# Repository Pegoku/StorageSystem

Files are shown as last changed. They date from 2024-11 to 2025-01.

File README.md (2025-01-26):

# Smart Storage System

## Overview
This is a versatile and customizable Storage System. It has the ability to combine multiple Storage Systems via the use of ESP32 (a cheap microcontroller) as controllers for the neopixels (indicators). It has a simple but useful WebUI and an API. The storage bins are compatible with Gridfinity 1x4 bins.

## Features
- [x] **Gridfinity Compatible**: Easily integrates with the Gridfinity storage system for modular storage.
- [x] **Parametric Design**: Easily customizable bins.
- [x] **ESP32 Controlled**: Scalable system using ESP32 as wireless controllers.
- [x] **Neopixels**: Dynamic lighting indicators.
- [x] **Web UI to Manage Storage**: User-friendly web interface for managing the items.
- [x] **API**: Simple to use API.
- [x] **Node PCB**: Simple ESP32-Wroom based PCB with the necessary connectors.

## Media
<details>
    <summary>Main Website</summary>

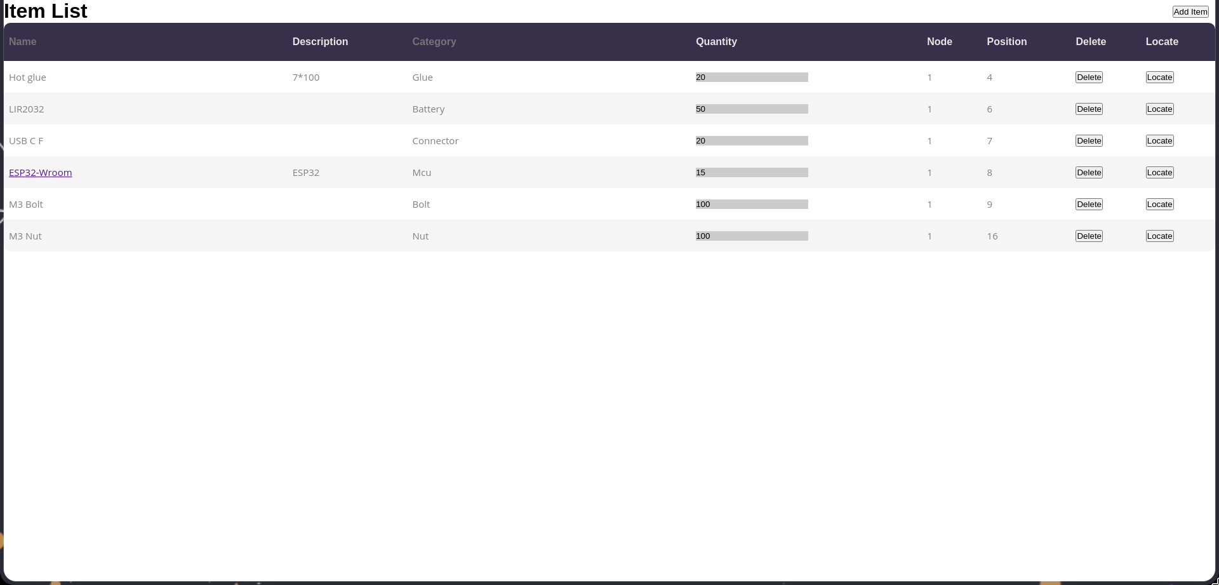
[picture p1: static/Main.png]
Main Website

</details>

<details>
    <summary>Add Item Menu</summary>

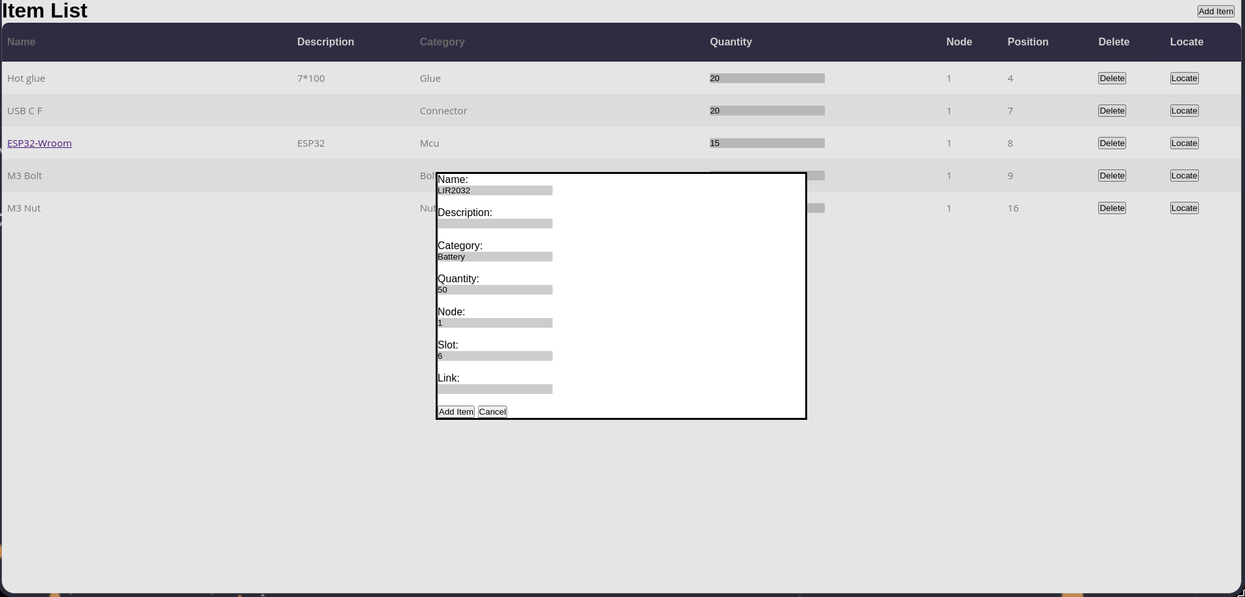
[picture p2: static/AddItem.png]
Add Item Menu

</details>

<details>
    <summary>Video</summary>

Video (https://cloud-f5ibtbvt0-hack-club-bot.vercel.app/0video.mp4)

</details>

## API Endpoints

### List Storage Items
- **Endpoint**: `/api/list`
- **Method**: `GET`
- **Description**: Retrieves a list of all storage items. Supports optional query parameters for filtering by category, node, and position.
- **Query Parameters**:
  - `category` (optional): Filter items by category.
  - `node` (optional): Filter items by node.
  - `position` (optional): Filter items by position.
  - `id` (optional): Filter items by ID:
### Locate Item by ID (GET)
- **Endpoint**: `/api/locateget`
- **Method**: `GET`
- **Description**: Locates an item by its ID and sends a request to the corresponding node to locate the item.
- **Query Parameters**:
  - `id` (required): The ID of the item to locate.

### List Nodes
- **Endpoint**: `/api/nodes`
- **Method**: `GET`
- **Description**:  Retrieves a list of all nodes. Supports optional query parameter for filtering by ID.
- **Query Parameters**:
    - `id` (optional): Filter nodes by ID.

### Add Storage Item
- **Endpoint**: `/api/additem`
- **Method**: `POST`
- **Description**: Adds a new storage item to the database.
- **Request Body** (JSON):
  ```json
  {
    "name": "string",
    "description": "string",
    "category": "string",
    "quantity": "integer",
    "node": "integer",
    "position": "integer",
    "url": "string",
    "slots": "array"

  }
  ```

### Add Node
- **Endpoint**: `/api/addnode`
- **Method**: `POST`
- **Description**:  Adds a new node to the database or updates an existing node if the ID already exists.
- **Request Body** (JSON):
  ```json
    {
      "id": "integer",
      "ip": "string",
      "positions": "integer"
    }
  ```

### Delete Storage Item
- **Endpoint**: `/api/delete`
- **Method**: `POST`
- **Description**:   Deletes a storage item by its ID.
- **Request Body** (JSON):
  ```json
    {
      "id": "integer"
    }
  ```

### Edit Storage Item
- **Endpoint**: `/api/edit`
- **Method**: `POST`
- **Description**:  Edits an existing storage item by its ID.
- **Request Body** (JSON):
  ```json
    {
    "id": "integer",
    "name": "string",
    "description": "string",
    "category": "string",
    "quantity": "integer",
    "node": "integer",
    "position": "integer",
    "url": "string",
    "slots": "array"
    }   
  ```

### Move Storage Item
- **Endpoint**: `/api/move`
- **Method**: `POST`
- **Description**:  Moves a storage item to a different node and position.
- **Request Body** (JSON):
  ```json
    {
    "id": "integer",
    "node": "integer",
    "position": "integer"
    }
  ```

### Locate Item by ID (POST)
- **Endpoint**: `/api/locate`
- **Method**: `POST`
- **Description**:  Locates an item by its ID and sends a request to the corresponding node to locate the item.
- **Request Body** (JSON):
  ```json
    {
    "id": "integer"
    }
  ```

## Getting Started

### Prerequisites
- [PlatformIO](https://platformio.org) installed on your development environment.
- ESP32 DevBoard or [Node PCB](https://github.com/Pegoku/StorageSystem/tree/master/PCB/NodePCB) .
- Neopixels (WS2812B) or [Indicator PCB](https://github.com/Pegoku/StorageSystem/tree/master/PCB/Indicators).
- Some wire.
- Edit Code/App/static/script.js `server` variable
- Edit Code/Node/include/.env with the correct settings

### Docker (API + Website)
1. Clone the repository:
    ```sh
    git clone https://github.com/Pegoku/StorageSystem.git
    cd StorageSystem
    ```
2. Build and run the Docker containers:
  ```sh
  docker compose up -d --build
  ```

### API 
1. Clone the repository:
    ```sh
    git clone https://github.com/Pegoku/StorageSystem.git
    cd StorageSystem/Code/Server
    ```
2. Create a Python virtual environment and install the requirements:
    ```sh
    python3 -m venv .venv
    source .venv/bin/activate
    pip install -r requirements.txt
    ```
3. Run the main Python file:
    ```sh
    python3 main.py
    ```

### API (Docker)
1. Clone the repository:
  ```sh
  git clone https://github.com/Pegoku/StorageSystem.git
  cd StorageSystem
  ```
2. Build and run the Docker container:
  ```sh
  docker buildx build -t storagesystem:server -f server.Dockerfile .
  docker run -p 5505:5505 -v ./database.db:/app/database.db storagesystem:server
  ```
3. The API should now be running and accessible at `http://localhost:5505`.

### ESP32
1. Clone the repository:
    ```sh
    git clone https://github.com/Pegoku/StorageSystem.git
    cd StorageSystem
    ```
2. Install the required libraries and dependencies:
    ```sh
    platformio run
    ```
3. Connect your ESP32 to your computer.
4. Edit the `include/.env.template` file and rename it to `include/.env`.
5. Upload the firmware to the ESP32:
    ```sh
    platformio run --target upload
    ```
6. Open the serial monitor to check if the installation was successful:
    ```sh
    platformio device monitor
    ```

### Website
1. Clone the repository:
    ```sh
    git clone https://github.com/Pegoku/StorageSystem.git
    cd StorageSystem/Code/App
    ```
2. Create a Python virtual environment and install the requirements:
    ```sh
    python3 -m venv .venv
    source .venv/bin/activate
    pip install -r requirements.txt
    ```
3. Run the main Python file:
    ```sh
    python3 main.py
    ```

### Website (Docker)
1. Clone the repository:
  ```sh
  git clone https://github.com/Pegoku/StorageSystem.git
  cd StorageSystem
  ```
2. Build and run the Docker container:
  ```sh
  docker buildx build -t storagesystem:app -f app.Dockerfile .
  docker run -p 5506:5506 storagesystem:app
  ```
3. The website should now be running and accessible at `http://localhost:5506`.

## Contributing
Contributions are welcome! Please fork the repository and submit a pull request with your changes.

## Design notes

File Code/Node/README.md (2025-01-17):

Code for the ESP32
## Important

Make sure to configure the include/.env file correctly

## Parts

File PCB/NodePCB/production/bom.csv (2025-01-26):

Designator | Footprint | Quantity | Value | LCSC Part #
D1 | SOD-323_L1.8-W1.3-LS2.5-RD | 1 | NSR0320MW2T1G | C48192
J1 | PinHeader_1x04_P2.54mm_Horizontal | 1 | Conn_01x04
J2, J3 | PinHeader_1x03_P2.54mm_Horizontal | 2 | Conn_01x03_Pin
J4, J5 | PinHeader_1x10_P2.54mm_Vertical | 2 | Conn_01x10
LED1 | LED0805-R-RD | 1 | FC-2012HRK-620D | C84256
R1 | 0603 | 1 | 1k
R2, R3 | 0603 | 2 | 5.1k
R4 | 0603 | 1 | 68
SW1, SW2 | SW-SMD_L3.9-W3.0-P4.45 | 2 | TS-1088-AR02016 | C720477
U1 | COMM-SMD_ESP-WROOM-32D | 1 | ESP-WROOM-32E | C19949066
U2 | SOT-223-3_L6.5-W3.4-P2.30-LS7.0-BR | 1 | LM2940S-3.3 | C596335
USB1 | TYPE-C-SMD_TYPE-C-6P_5 | 1 | TYPE-C 6P(073) | C668623

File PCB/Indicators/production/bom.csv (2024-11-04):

Designator | Footprint | Quantity | Value | LCSC Part #
C1 | 0603 | 1 | C | C2844328
J1, J2 | PinHeader_1x03_P2.54mm_Horizontal | 2 | Conn_01x03
J3, J4 | PinSocket_1x03_P2.54mm_Horizontal | 2 | Conn_01x03
LED1 | LED-SMD_4P-L5.0-W5.0-BL_TC5050RGB | 1 | WS2812B-B | C114586
TP1, TP2, TP3, TP4, TP5, TP6 | TestPoint_Pad_D1.5mm | 6 | TestPoint

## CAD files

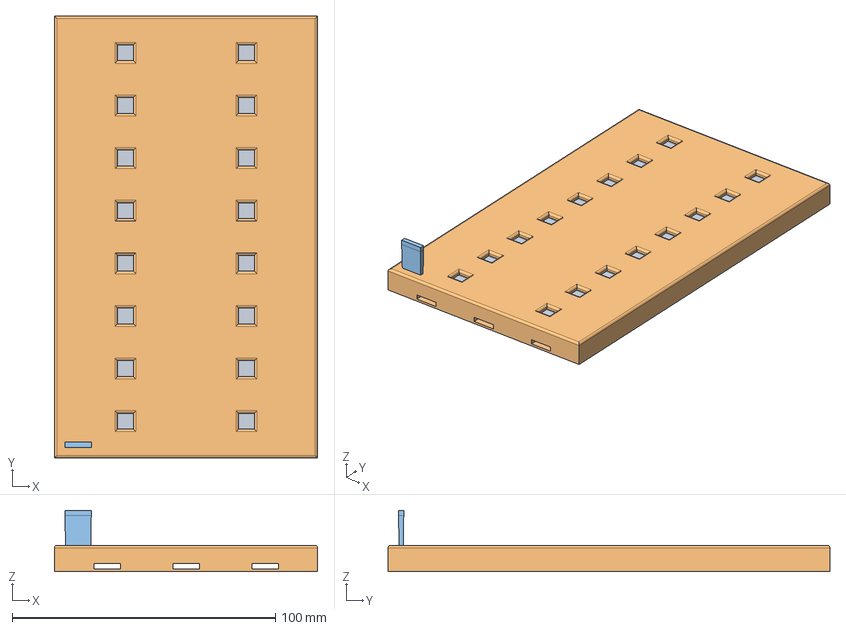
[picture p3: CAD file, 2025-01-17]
3D/Main.FCStd
100.0 x 168.0 x 23.3 mm
SlotIndicatorBack
SlotIndicatorCover
SlotIndicatorPin

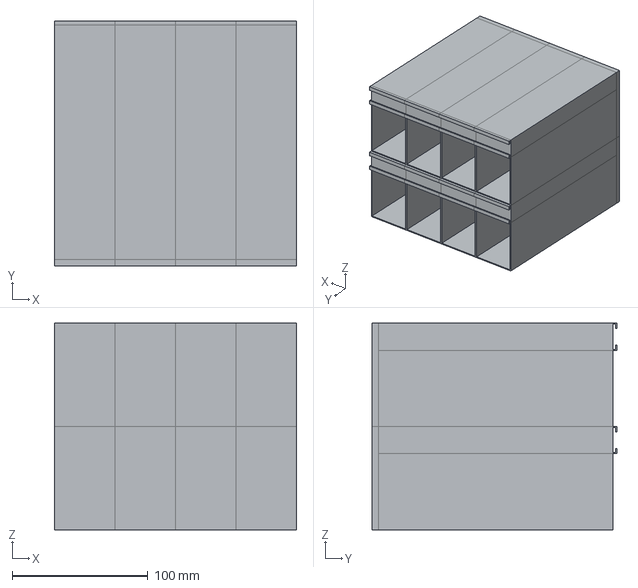
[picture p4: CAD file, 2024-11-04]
3D/Main-Body004.step
178.0 x 180.5 x 152.0 mm

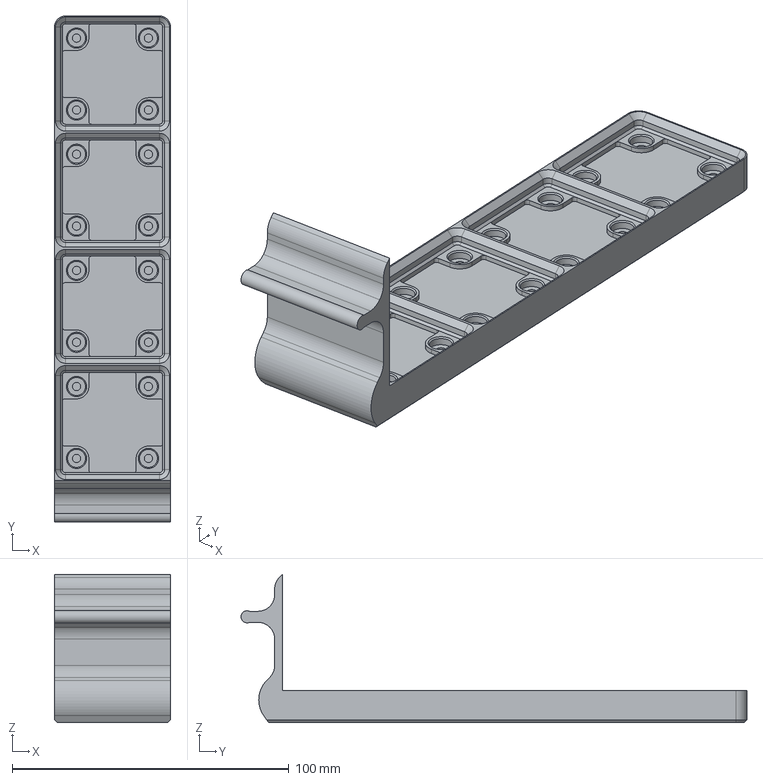
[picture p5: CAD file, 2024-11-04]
3D/Main-PartBody001.step
42.0 x 183.0 x 53.6 mm

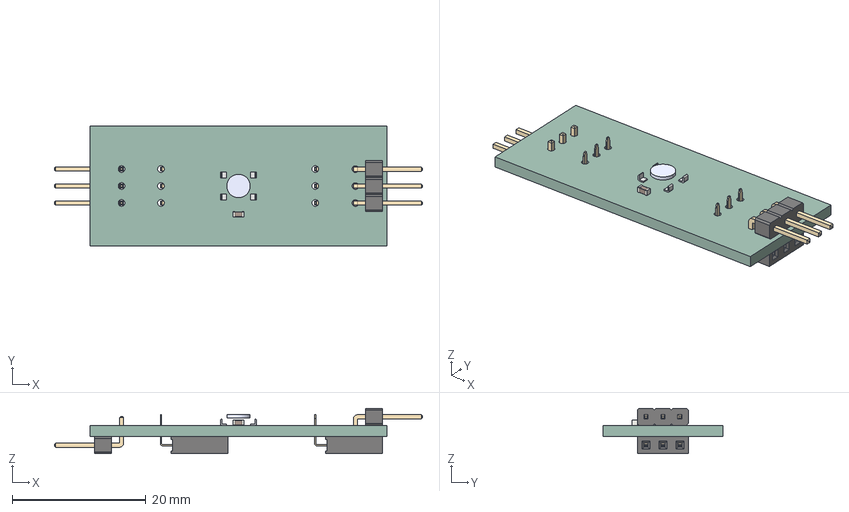
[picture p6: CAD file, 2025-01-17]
PCB/Indicators/Indicators.step
55.1 x 18.0 x 6.78 mm
C_0603_1608Metric
PinHeader_1x03_P254mm_Horizontal x 2
LED-SMD_4P-L5.0-W5.0-BL_TC5050RGB
PinSocket_1x03_P254mm_Horizontal x 2
Indicators_PCB

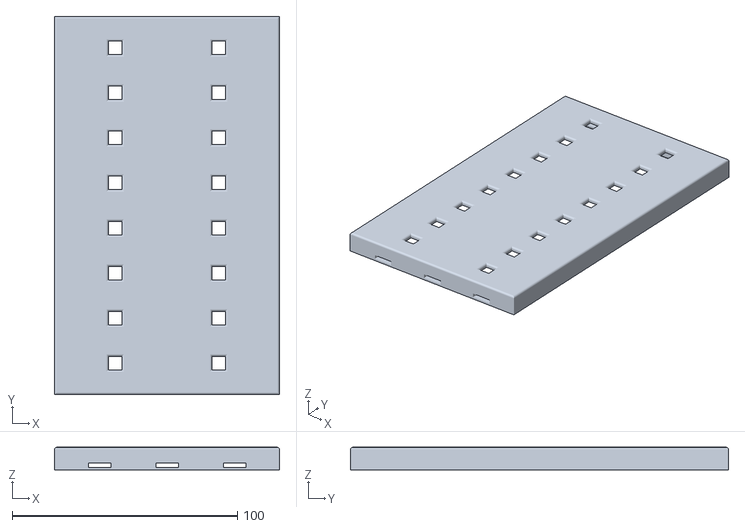
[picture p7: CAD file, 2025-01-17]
3D/SlotIndicatorCover.stl
100.0 x 168.0 x 10.0

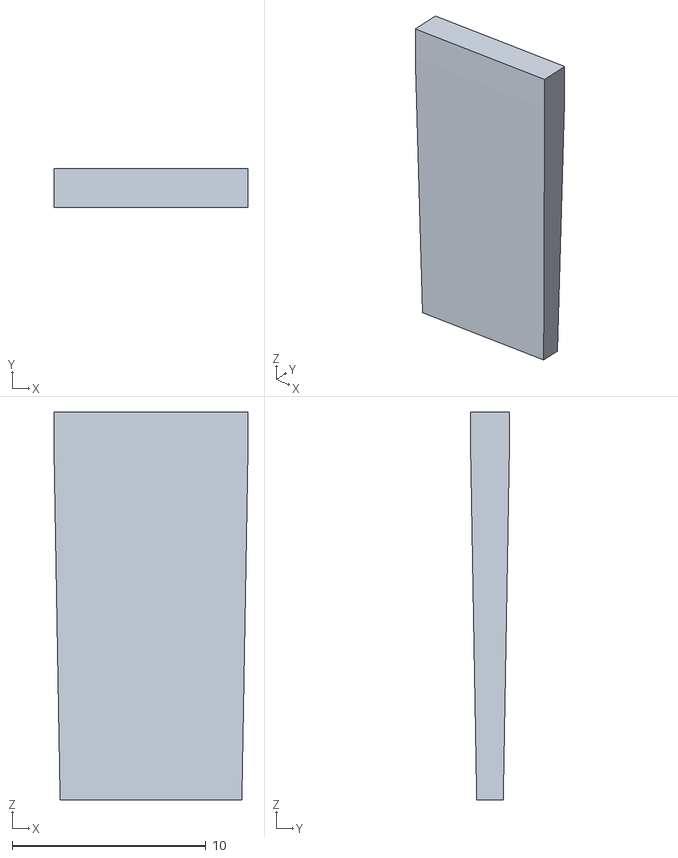
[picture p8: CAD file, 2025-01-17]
3D/SlotIndicatorPin.stl
10.0 x 2.00 x 20.0

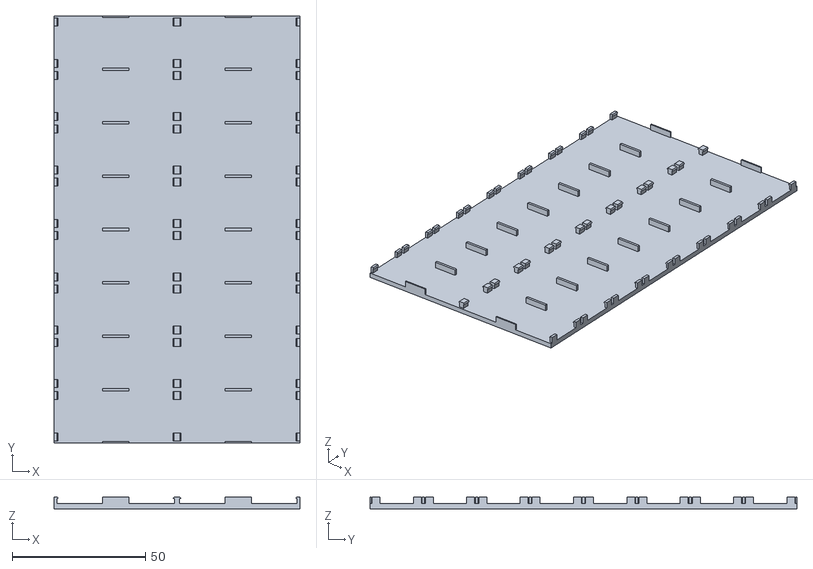
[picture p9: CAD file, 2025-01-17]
3D/SlotIndicatorBack.stl
92.0 x 160.0 x 4.50

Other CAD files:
3D/Tray.step
3D/Box.step
3D/Box.stl
3D/Tray.stl

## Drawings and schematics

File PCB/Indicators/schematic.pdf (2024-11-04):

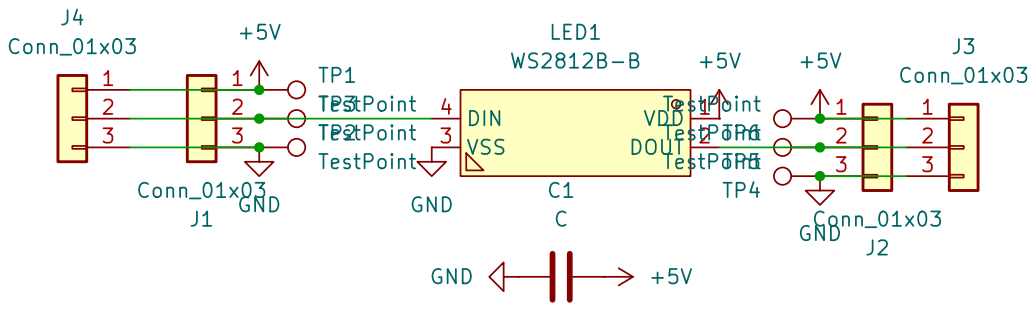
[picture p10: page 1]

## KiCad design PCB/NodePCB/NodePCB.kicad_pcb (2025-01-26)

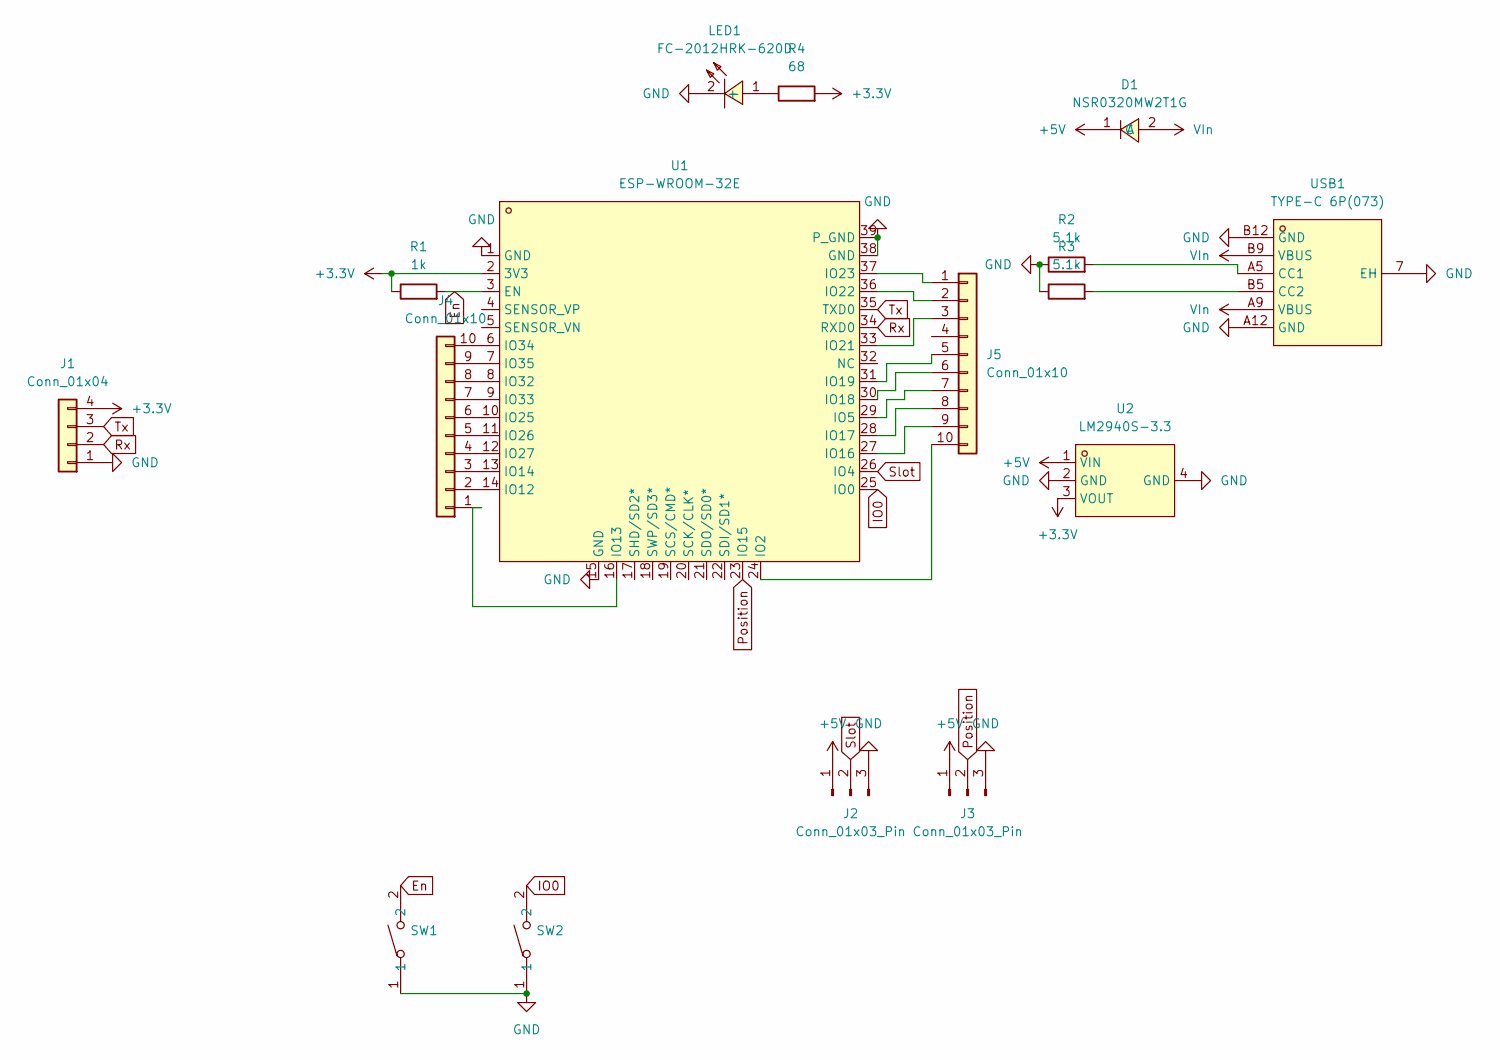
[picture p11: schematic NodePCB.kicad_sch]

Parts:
D1: NSR0320MW2T1G; SOD-323_L1.8-W1.3-LS2.5-RD; LCSC Part C48192
J1: Conn_01x04; PinHeader_1x04_P2.54mm_Horizontal
J2, J3: Conn_01x03_Pin; PinHeader_1x03_P2.54mm_Horizontal
J4, J5: Conn_01x10; PinHeader_1x10_P2.54mm_Vertical
LED1: FC-2012HRK-620D; LED0805-R-RD; LCSC Part C84256
R1: 1k; R_0603_1608Metric
R2, R3: 5.1k; R_0603_1608Metric
R4: 68; R_0603_1608Metric
SW1, SW2: TS-1088-AR02016; SW-SMD_L3.9-W3.0-P4.45; LCSC Part C720477
U1: ESP-WROOM-32E; COMM-SMD_ESP-WROOM-32D; LCSC Part C19949066
U2: LM2940S-3.3; SOT-223-3_L6.5-W3.4-P2.30-LS7.0-BR; LCSC Part C596335
USB1: TYPE-C 6P(073); TYPE-C-SMD_TYPE-C-6P_5; LCSC Part C668623

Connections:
+3.3V: J1.4, R1.1, R4.2, U1.2 (3V3), U2.3 (VOUT)
+5V: D1.1 (C), J2.1, J3.1, U2.1 (VIN)
En: R1.2, SW1.2, U1.3 (EN)
GND: J1.1, J2.3, J3.3, LED1.2 (-), R2.1, R3.1, SW1.1, SW2.1, U1.1 (GND), U1.15 (GND), U1.38 (GND), U1.39 (P_GND), U2.2 (GND), U2.4 (GND), USB1.7 (EH), USB1.A12 (GND), USB1.B12 (GND)
IO0: SW2.2, U1.25 (IO0)
unnamed: J4.1, U1.16 (IO13)
unnamed: J4.2, U1.14 (IO12)
unnamed: J4.3, U1.13 (IO14)
unnamed: J4.4, U1.12 (IO27)
unnamed: J4.5, U1.11 (IO26)
unnamed: J4.6, U1.10 (IO25)
unnamed: J4.7, U1.9 (IO33)
unnamed: J4.8, U1.8 (IO32)
unnamed: J4.9, U1.7 (IO35)
unnamed: J4.10, U1.6 (IO34)
unnamed: J5.1, U1.37 (IO23)
unnamed: J5.2, U1.36 (IO22)
unnamed: J5.3, U1.33 (IO21)
unnamed: J5.5, U1.31 (IO19)
unnamed: J5.6, U1.30 (IO18)
unnamed: J5.7, U1.29 (IO5)
unnamed: J5.8, U1.28 (IO17)
unnamed: J5.9, U1.27 (IO16)
unnamed: J5.10, U1.24 (IO2)
unnamed: LED1.1 (+), R4.1
unnamed: R2.2, USB1.A5 (CC1)
unnamed: R3.2, USB1.B5 (CC2)
Position: J3.2, U1.23 (IO15)
Rx: J1.2, U1.34 (RXD0)
Slot: J2.2, U1.26 (IO4)
Tx: J1.3, U1.35 (TXD0)
VIn: D1.2 (A), USB1.A9 (VBUS), USB1.B9 (VBUS)

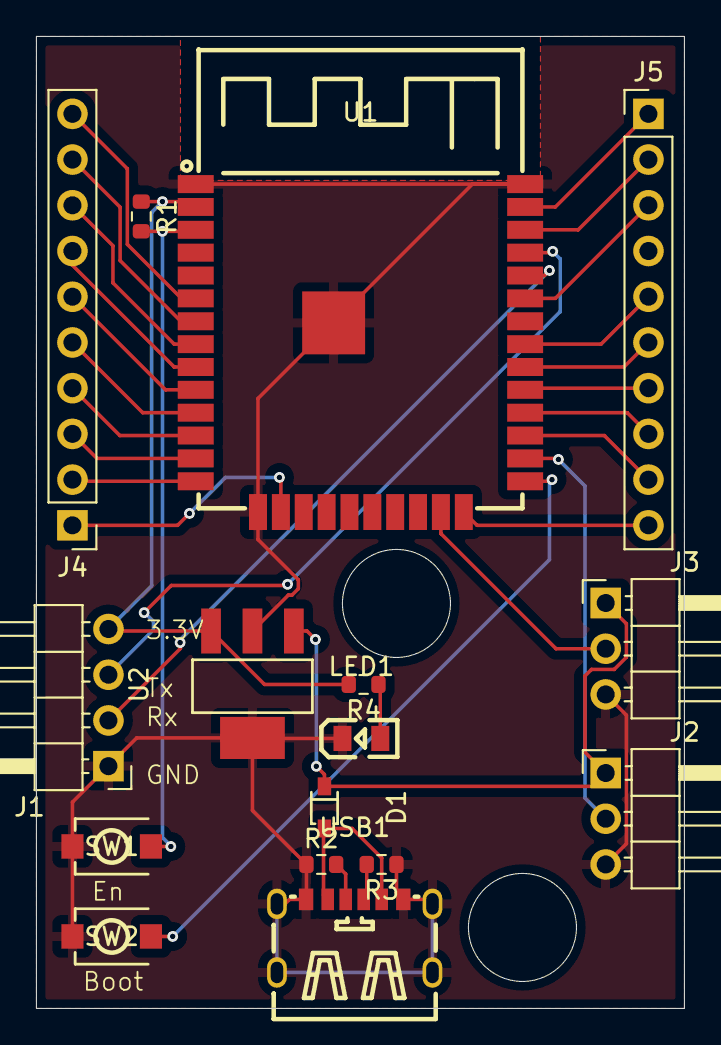
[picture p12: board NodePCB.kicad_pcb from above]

Board: 2 copper layers, 36.0 x 54.0 mm, 16 parts (0 on the bottom side), 32 nets.

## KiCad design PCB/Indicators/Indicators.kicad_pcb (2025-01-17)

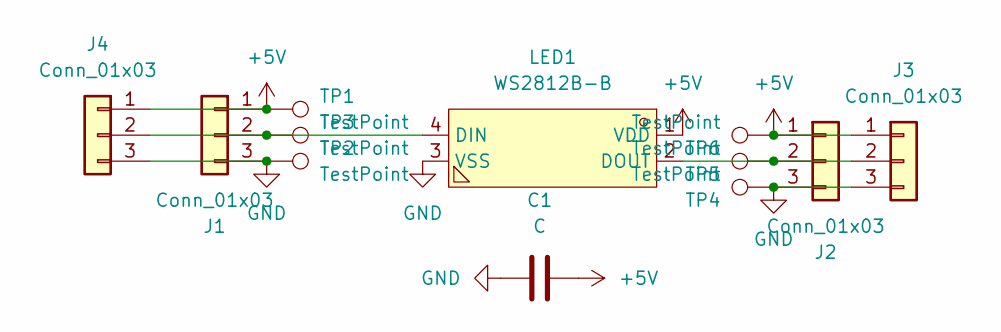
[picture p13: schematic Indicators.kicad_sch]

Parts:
C1: C; C_0603_1608Metric; LCSC C2844328
J1, J2: Conn_01x03; PinHeader_1x03_P2.54mm_Horizontal
J3, J4: Conn_01x03; PinSocket_1x03_P2.54mm_Horizontal
LED1: WS2812B-B; LED-SMD_4P-L5.0-W5.0-BL_TC5050RGB; LCSC Part C114586
TP1, TP2, TP3, TP4, TP5, TP6: TestPoint; TestPoint_Pad_D1.5mm

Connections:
+5V: C1.2, J1.1, J2.1, J3.1, J4.1, LED1.1 (VDD), TP1.1, TP6.1
GND: C1.1, J1.3, J2.3, J3.3, J4.3, LED1.3 (VSS), TP2.1, TP4.1
unnamed: J1.2, J4.2, LED1.4 (DIN), TP3.1
unnamed: J2.2, J3.2, LED1.2 (DOUT), TP5.1

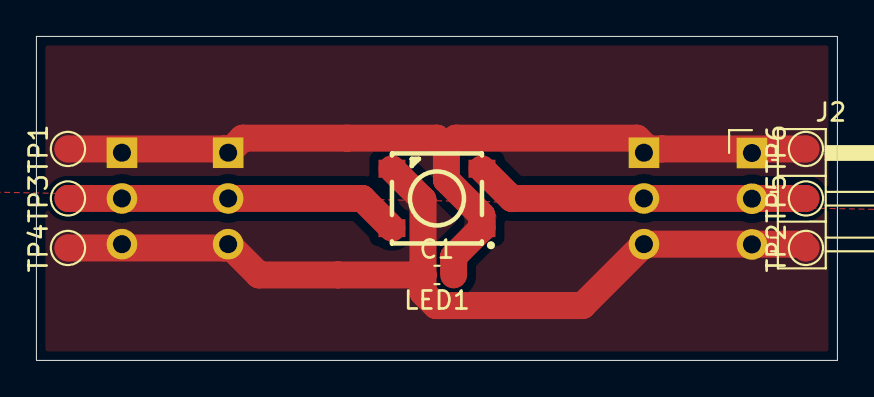
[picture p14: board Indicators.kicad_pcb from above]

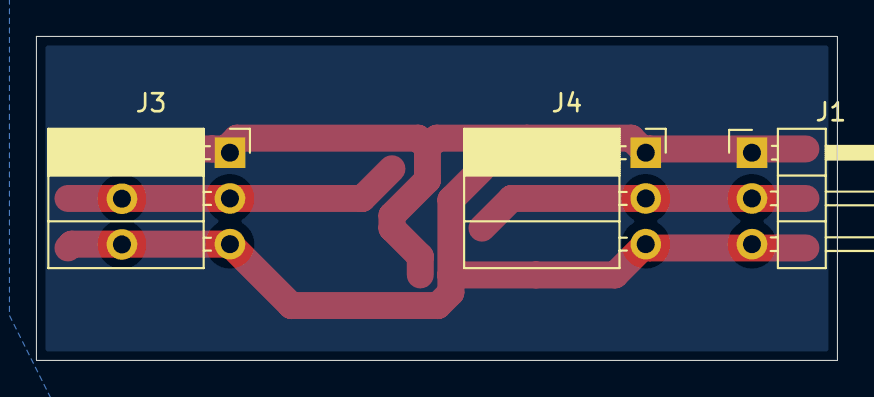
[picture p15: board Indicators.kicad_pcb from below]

Board: 2 copper layers, 44.5 x 18.0 mm, 12 parts (3 on the bottom side), 4 nets.

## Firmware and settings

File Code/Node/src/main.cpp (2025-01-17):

#include <Arduino.h>
#include <Adafruit_NeoPixel.h>
#include <WiFi.h>
#include <HTTPClient.h>
#include <ArduinoJson.h>
#include <WebServer.h>

#include <.env>

Adafruit_NeoPixel strip = Adafruit_NeoPixel(positions, 15, NEO_GRB + NEO_KHZ800);
Adafruit_NeoPixel slotLed = Adafruit_NeoPixel(16, 4, NEO_GRB + NEO_KHZ800);
WebServer server(4444);

const size_t capacity = JSON_OBJECT_SIZE(10) + 200;
StaticJsonDocument<capacity> jsonDocument;

char buffer[1024];

void locate(int position, JsonArray slotArray)
{
    position = position - 1;

    if (position < 0 || position >= positions)
    {
        Serial.println("Invalid position");
        server.send(400, "text/plain", "Invalid position");
        return;
    }
    else
    {
        server.send(200, "application/json", "{\"success\": true}");

        Serial.println("Locating position " + String(position));
        strip.clear();
        strip.setPixelColor(position, strip.Color(5, 5, 5));
        strip.show();
        String slotArrayStr;
        serializeJson(slotArray, slotArrayStr);
        Serial.println("Locating slots " + slotArrayStr);
        for (size_t i = 0; i < slotArray.size(); i++)
        {
            slotLed.setPixelColor(slotArray[i].as<int>() - 1, slotLed.Color(5, 5, 5));
        }
        slotLed.show();

        delay(5505);
        strip.clear();
        strip.show();
        slotLed.clear();
        slotLed.show();
    }
}

void handlePost()
{
    Serial.println("POST request received");
    if (server.hasArg("plain") == false)
    {
        server.send(400, "text/plain", "Payload not found");
        return;
    }

    Serial.println("Payload found");
    String payload = server.arg("plain");
    deserializeJson(jsonDocument, payload);
    Serial.println("Deserialized JSON");
    Serial.println(payload);

    int position = jsonDocument["position"];
    JsonArray slotJsonArray = jsonDocument["slot"].as<JsonArray>();
    int slotArray[slotJsonArray.size()];
    for (size_t i = 0; i < slotJsonArray.size(); i++)
    {
        slotArray[i] = slotJsonArray[i];
    }

    Serial.println(jsonDocument["position"].as<int>());
    for (size_t i = 0; i < slotJsonArray.size(); i++)
    {
        Serial.println(slotArray[i]);
    }

    locate(position, slotJsonArray);
}

void setupServer()
{
    Serial.println("Setting up server");
    server.on("/locate", HTTP_POST, handlePost);
    server.begin();
    Serial.println("Server started");
}

void setup()
{
    Serial.begin(115200);
    delay(1000);
    Serial.println("Hello World");

    strip.begin();

    WiFi.begin(ssid, password);

    while (WiFi.status() != WL_CONNECTED)
    {
        delay(1000);
        Serial.println("Connecting to WiFi...");
    }

    Serial.println("Connected to WiFi");

    Serial.println(WiFi.localIP());
    delay(1000);

    String nodeInfo = "{\"id\": " + String(node) + ", \"ip\": \"" + WiFi.localIP().toString() + "\", \"positions\": " + String(positions) + "}";
    if (WiFi.status() == WL_CONNECTED)
    {
        HTTPClient http;
        http.begin("http://" + String(server_IP) + ":" + String(server_port) + "/api/addnode");
        http.addHeader("Content-Type", "application/json");
        int httpCode = http.POST(nodeInfo);
        if (httpCode > 0)
        {
            String payload = http.getString();
            Serial.println(payload);
            http.end();

            JsonDocument doc;
            DeserializationError error = deserializeJson(doc, payload);

            if (!error)
            {
                bool success = doc["success"];
                if (success)
                {
                    Serial.println("Node added successfully");
                }
                else
                {
                    Serial.println("Check logs. Possible error in adding node");
                    // while (true)
                    // {
                    //     Serial.println(payload);
                    //     strip.fill(strip.Color(255, 0, 0), 0, positions);
                    //     strip.show();
                    //     delay(500);
                    //     strip.fill(strip.Color(0, 0, 0), 0, positions);
                    //     strip.show();
                    //     delay(500);
                    // }
                }
            }
            else
            {
                Serial.println("Failed to parse JSON response");
            }
        }
        else
        {
            Serial.println("HTTP request failed");
        }
    }
    else
    {
        Serial.println("WiFi not connected");
    }

    setupServer();
}

void loop()
{
    server.handleClient();
}

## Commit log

2024-11-04 working filtering system
2024-12-11 fix readme
    [Main.FCStd]
2024-12-14 add edit button
2024-12-14 better link filter
2024-12-17 fix bugs
    [Main.FCStd]
2025-01-17 modify models + finish
    [Main.FCStd, SlotIndicatorBack.stl, SlotIndicatorCover.stl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]
2025-01-17 edit default port for compatibility
    [Indicators.kicad_pcb, Indicators.step, Tray.step]
2025-01-26 Added Node PCB
    [NodePCB.kicad_pcb, NodePCB.kicad_sch, bom.csv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]
